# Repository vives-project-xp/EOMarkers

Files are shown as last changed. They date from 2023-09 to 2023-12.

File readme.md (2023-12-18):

# **EO-Markers**

> Develop small standalone boxes that light up when someone approaches them.
> The boxes can be fitted with a plexi with Electronics-ICT and a
> direction indication via an arrow.

# Layout Github Repo

```bash
.
├── 3d tekening
│   ├── 3D_Bottom.png
│   ├── 3D_Main.png
│   └── README.md
├── Affiche
│   └── EO Markers Affiche.png
├── AndroidStudio
│   ├── EO-Markers
│   │   └── app
│   └── README.md
├── Arduino
│   ├── EO-Markers
│   │   ├── EO-Markers.cpp
│   │   └── EXAMPLE-config.h
│   └── README.md
├── img
│   ├── qr.png
│   └── project_canvas.png
│   └── potentiometers.jpg
│   └── schakelaar.jpg
├── PCB
│   ├── PCB
|   ├── PCB_ESP32-C3-DevKitM-1
│   ├── PCB_ESP32-C3-DevKitC-02
│   └── README.md
└── readme.md
```

# Table of contents

- [Planning](#planning)
- [Canvas](#canvas)
- [Affiche](#affiche)
- [How to use](#how-to-use)
- [3D Tekening](#3d-drawing)
- [Android Studio](#android-studio)
- [Arduino](#arduino)
- [PCB](#pcb)

# Planning

- sprint 1 - Uitwerken concept & BOM lijst doorgeven voor bestellingen
- sprint 2 - Van prototype naar product
- sprint 3 - Product afwerken en test klaar maken
- sprint 4 - Debuggen, documenteren

# Canvas

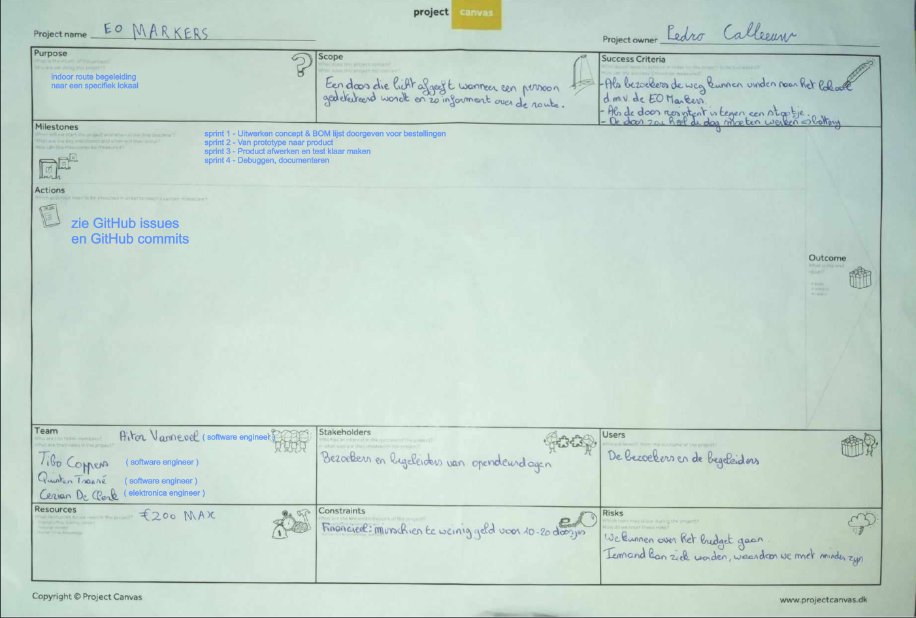
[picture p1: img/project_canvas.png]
Canvas


# Affiche

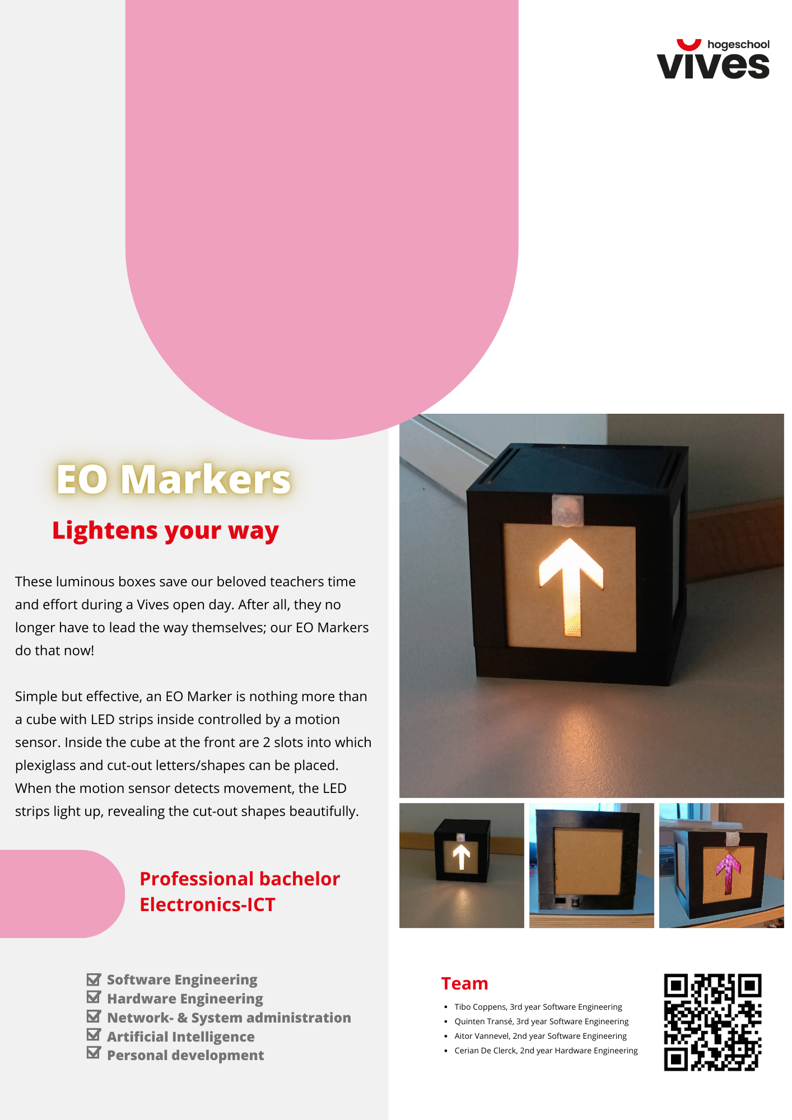
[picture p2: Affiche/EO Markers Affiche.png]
Affiche


# How to use

1. It is important that the batteries are fully charged, as they are rechargeable. A USB-C port is provided as an alternative power supply.
2. Turn the switch on.

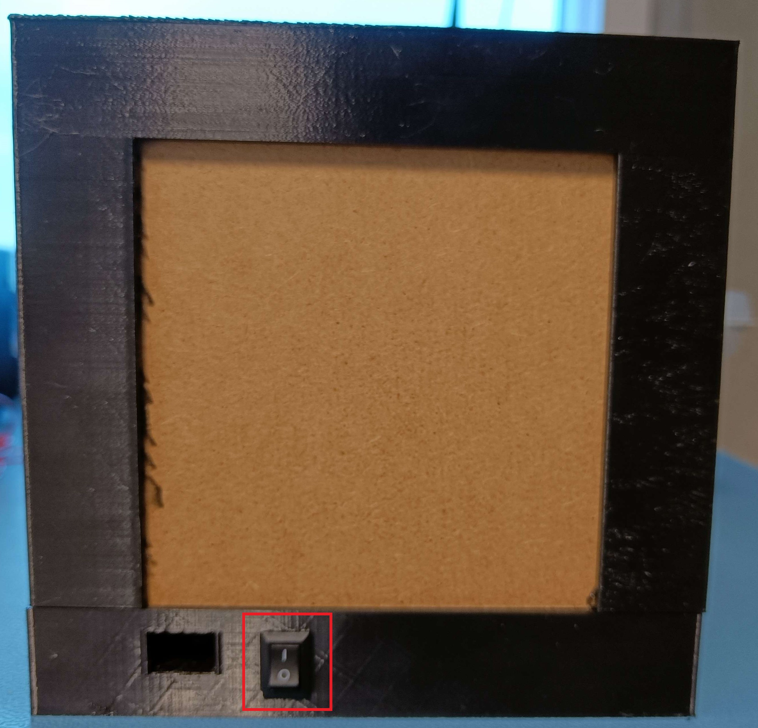
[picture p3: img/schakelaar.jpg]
schakelaar


3. Wait about 10 seconds. The LED strips will then light up whenever the sensor, attached to the front of the marker, detects movement.
4. You can change the distance at which the sensor detects movement and the duration of lighting by turning the potentiometers as shown in the image.

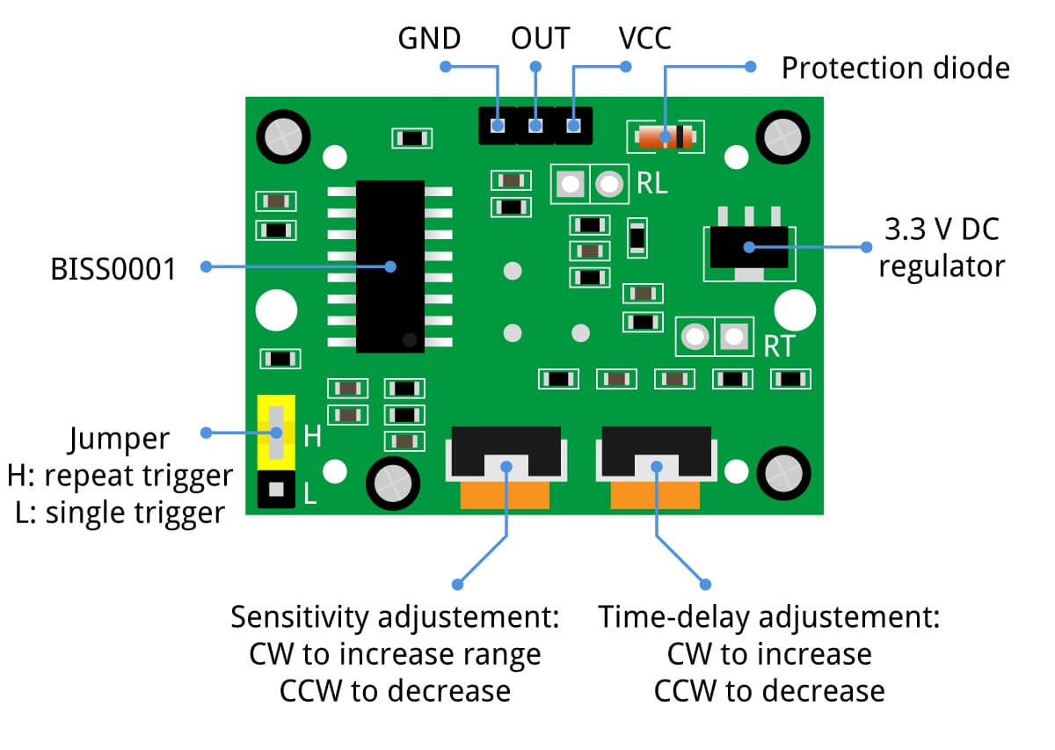
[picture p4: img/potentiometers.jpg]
potentiometers


5. Each time the light goes out, there is a period of 2.5 seconds before the sensor can detect movement again.
6. After using the EO marker, switch it off and charge the batteries.

# 3D drawing 

more info: [3D Tekening](./3d%20tekening/readme.md)

This is the base of the cube. The sensor is placed in the small round hole, the LED strips stick to the inside of the posts and the cables are inserted through the middle part. A reflective film has been applied to this area, which helps to spread the light around. A diffuser (plexiglass) is slid into the furthest slot and a plywood wall, with or without directions, is placed in the nearest slot.

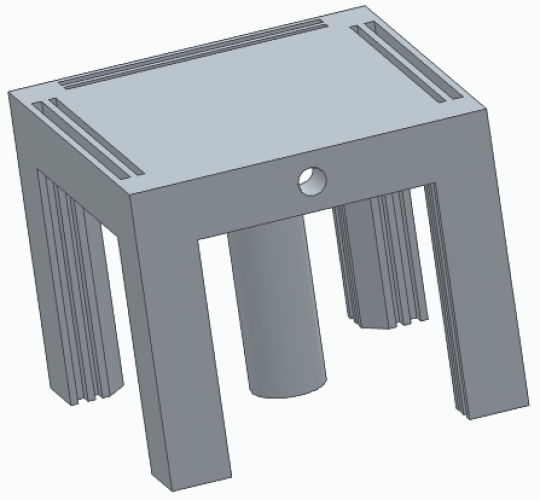
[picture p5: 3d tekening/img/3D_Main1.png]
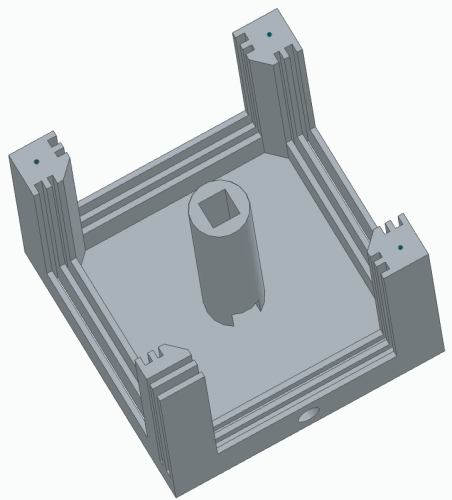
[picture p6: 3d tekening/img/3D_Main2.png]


This is the bottom of the cube. This is where the PCB, battery holder and cables end up. A hole is provided for a USB cable as secondary power. These 2 prints are screwed together with an M3 screw or bolt.

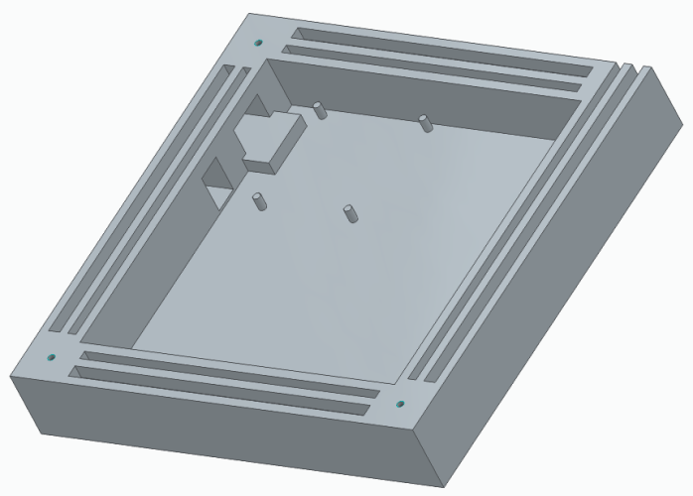
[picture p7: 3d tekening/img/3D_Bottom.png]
Bottom bottom


# Android Studio

more info: [Android Studio](./AndroidStudio/README.md)

# Arduino

more info: [Arduino](./Arduino/README.md)

# PCB

more info: [PCB](./PCB/README.md)

## PCB print

The PCB consists of a pair of connectors for the ESP, LED strip, sensor and USB-C port. These are female headers, so they fit in perfectly. The connectors are internally connected on the PCB. 

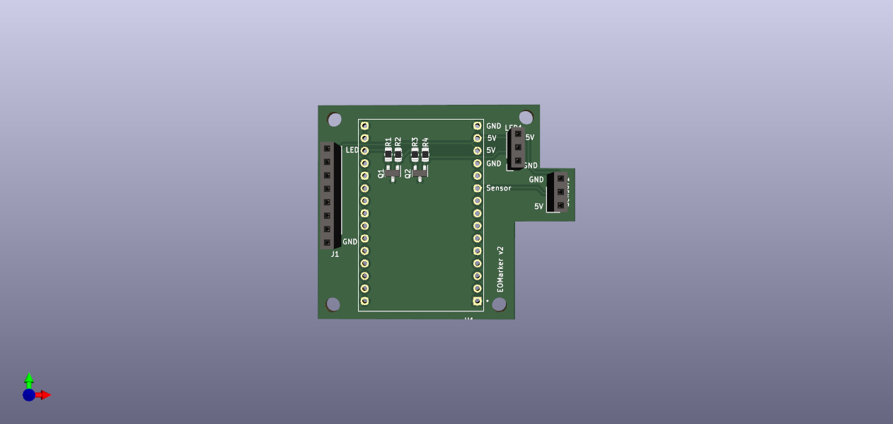
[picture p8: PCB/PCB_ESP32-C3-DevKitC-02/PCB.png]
PCB


## PCB schematic

The circuit consists of 1 ESP, powered by a USB cable or a 5V battery pack connected in parallel on the j1 connector with a diode from battery pack to connector (4 rechargeable AA batteries). 3 female headers for the LED strips, 3 female headers for the sensor, 8 female headers for the USB-C port and a diode to stop current to the batteries.

Measurements:
U LED-strips (off): 4,1V;
U LED-strips (on): 3,1V

U Batteries (leds off): 4.9V;
U Batteries (leds on): 4.3V

U Diode (leds off): 0.72V;
U Diode (leds on): 0.86V

U Sensor (leds off): 2.98V;
U Sensor (leds on): 2.55V

U ESP (leds off): 4.1V;
U ESP (leds on): 3.45V

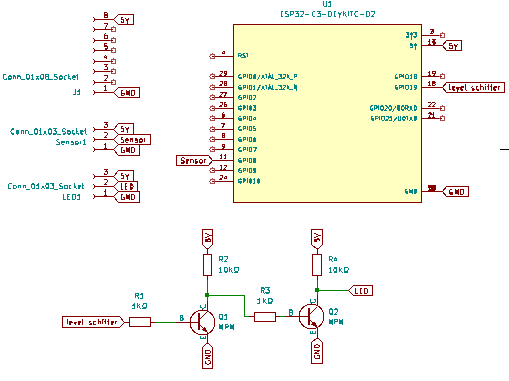
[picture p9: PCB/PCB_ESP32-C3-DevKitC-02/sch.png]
Schakeling


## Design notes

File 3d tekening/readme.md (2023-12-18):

# 3D drawing of EO-Marker

# Table of contents

- [Top part](#top)
- [Bottom Part](#bottom)
- [Wall](#wall)
- [Afmetingen](#afmetingen-metric)
- [Recommended Print Settings](#recommended-print-settings)

# Top

This is the main part of the cube. The sensor goes into the hole at the front with its cables going through the cylinder. A reflective foil is applied to this cylinder. The LED strips are located on the sloping side of the pillars. A diffuser (plexiglass) is placed in the furthest slot and a plywood wall, with or without directions, is placed in the nearest slot.

Top topTop top

# Bottom

This is the bottom of the cube. This is where the PCB and battery holder end up. These are glued in place with hot glue. There is a hole for a USB cable that functions as a secondary power and a hole for the switch. These 2 prints are screwed together with an M3 screw or bolt. The PCB is slid onto the pins with the USB-C connector on the platform. To the left of the switch, against the wall, the battery holder is glued with a margin between the 2 walls, so that it can be opened.

Bottom bottom

# Wall

This is the wall that blocks or allows light to pass through an arrow. This is laser cut from 3mm plywood. A reflective foil is also applied to this on the inside, so that the light can only escape through the arrow.

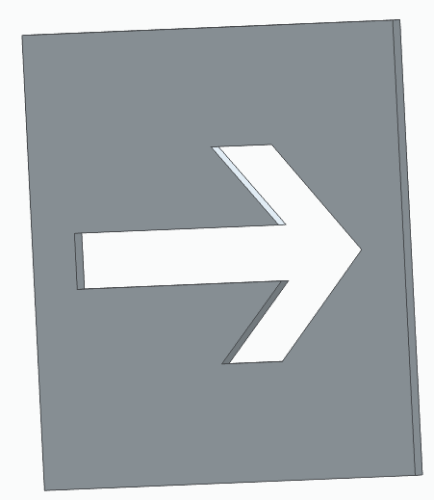
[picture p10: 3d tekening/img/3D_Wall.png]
Wall wall


# Afmetingen (metric)

The cube assembled is 150x150x150 mm in size. The walls have a size of 109x109x3 mm, of which 100x100 mm is visible.

# Recommended print settings

- Material: PLA
- Resolution: 0.15 - 0.20
- Infill density: 10%
- Infill pattern: tri-hexagon
- Support: tree
- No adhesion

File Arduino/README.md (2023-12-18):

# arduino (esp32) firmware

## table of contents

- [Setup and configuration](#setup-and-configuration)
  - [Install environment](#install-environment)
  - [Configure config.h](#configure-configh)
- [Install](#install)
- [Usage](#usage)
- [Flowchart](#flowchart)

## Setup and configuration

Clone this repository and open it in vscode with platformio installed.

Open ./EOMarker_firm in vscode.

### Install environment

1. Install vscode
2. Install platformio
3. Select esp32 board

### Configure config.h

1. Copy `config.h.example` to `config.h`
2. Configure `config.h` with your wifi and mqtt settings

Example config.h:
```cpp
namespace EOMarker {
  namespace Config  {
    const char * WIFI_SSID = "SSID";
    //const char * WIFI_PASS = "PASSWORD";
    const char * MQTT_BROKER = "BROKER_URL";
    const char * MQTT_PASS = "BROKER_PASSWORD";
    const unsigned int MQTT_PORT = BROKER_PORT;
    const char * MQTT_BASE_TOPIC = "MQTT_TOPIC";
    const String LOGINS = "{'MAC-ADDRESS':'PASSWORD','MAC-ADDRESS2':'PASSWORD2'}";
  };
};
```

## Install

1. Connect esp32 to computer
2. Run `pio run -t upload`

## Usage

1. Connect esp32 to custom pcb
2. Turn on switch

# Flowchart

this is an attempt to visualize the flow of the program (not accurate) 

```mermaid
graph TD
    A[main] --> B[setup]
    B --> C[loop]
    C --> D[setup_wifi]
    D --> E[keepWifiAlive]
    E --> F[checkSensor]
    F --> G[setColor]
    G --> H[sendAlive]
    H --> I[convertMac]
    I --> J[reconnect]
    J --> C
    J --> K[callback]
    K --> L[setColor]
    L --> H
    L --> M[sendAlive]
    M --> N[convertMac]
    N --> J
    N --> O[reconnect]
    O --> C
    O --> P[setColor]
    P --> Q[sendAlive]
    Q --> R[convertMac]
    R --> O
    R --> S[reconnect]
    S --> C
    S --> T[setColor]
    T --> U[sendAlive]
    U --> V[convertMac]
    V --> S
    V --> W[reconnect]
    W --> C
    W --> X[setColor]
    X --> Y[sendAlive]
    Y --> Z[convertMac]
    Z --> W
    
```

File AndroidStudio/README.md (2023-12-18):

# The android app
## Table of contents

- [How to install](#how-to-install)
- [How to use](#how-to-use)

## How to install

1. Download the apk file from the [EOMarker_v1.0.apk](EOMarker_V1.0.apk).
2. Install the apk file on your android device.

## How to use

1. Open the app.
2. Go to settings and fill in the broker credentials.

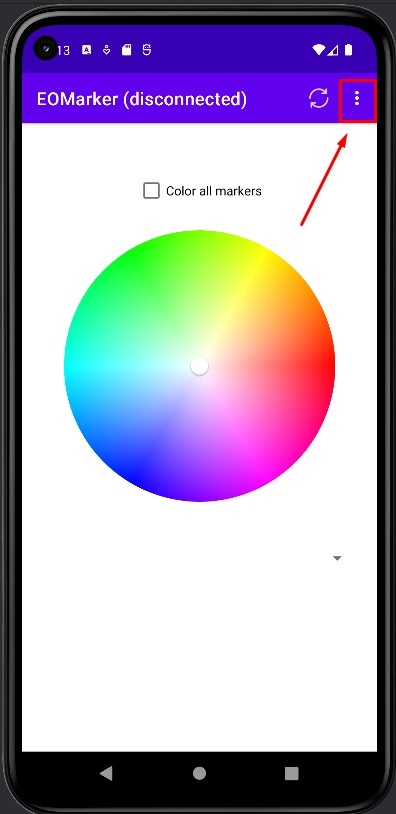
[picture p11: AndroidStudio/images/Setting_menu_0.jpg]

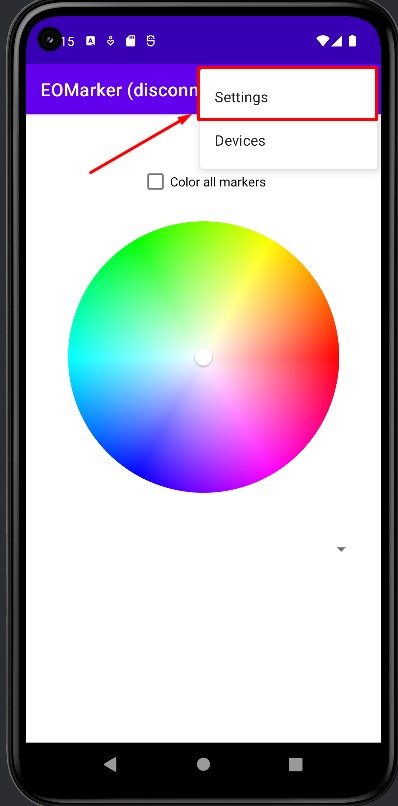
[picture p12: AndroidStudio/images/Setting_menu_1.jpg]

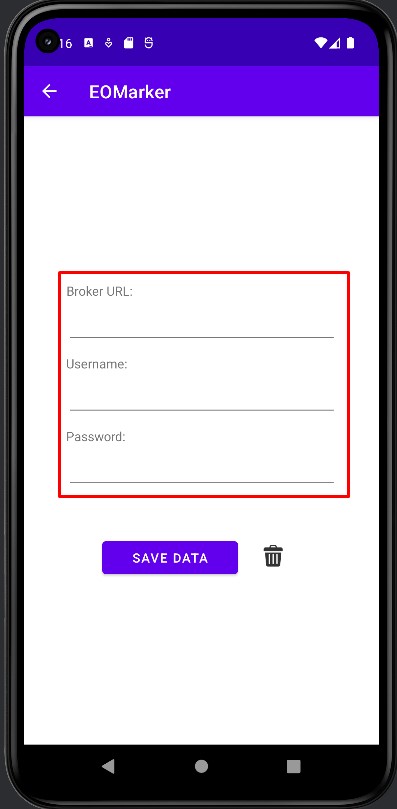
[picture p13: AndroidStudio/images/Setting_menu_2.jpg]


3. When you've filled in the credentials save them by pressing the save button.

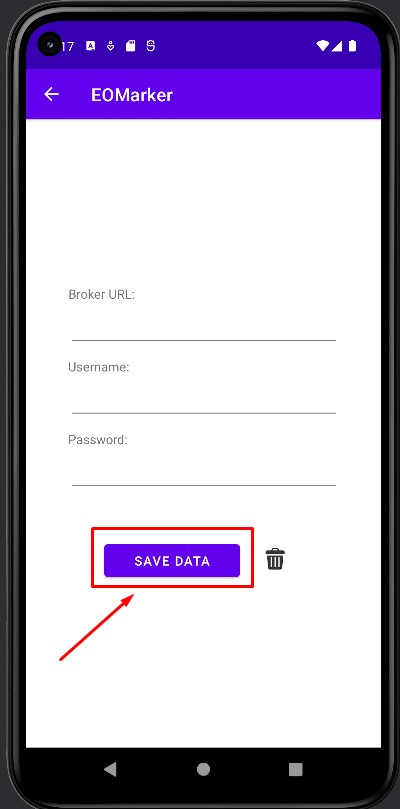
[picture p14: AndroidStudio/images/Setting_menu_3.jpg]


4. You should be redirected to the main menu and the status should now show connected instead of disconnected. 

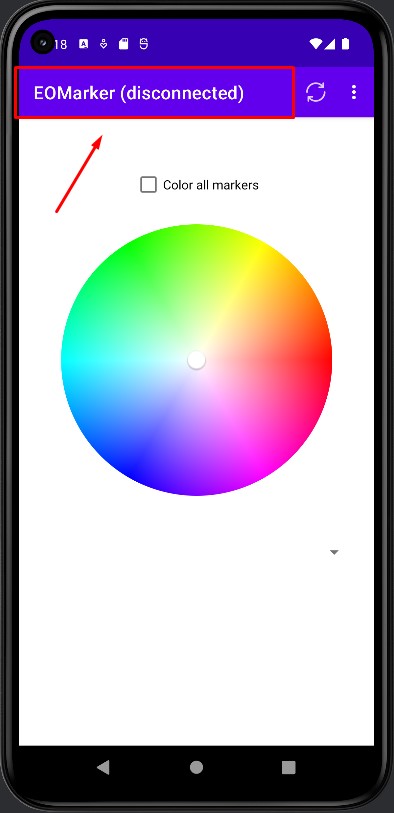
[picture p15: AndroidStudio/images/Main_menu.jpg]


5. Click the refresh button to discover the list of devices that are connected to the broker if available.

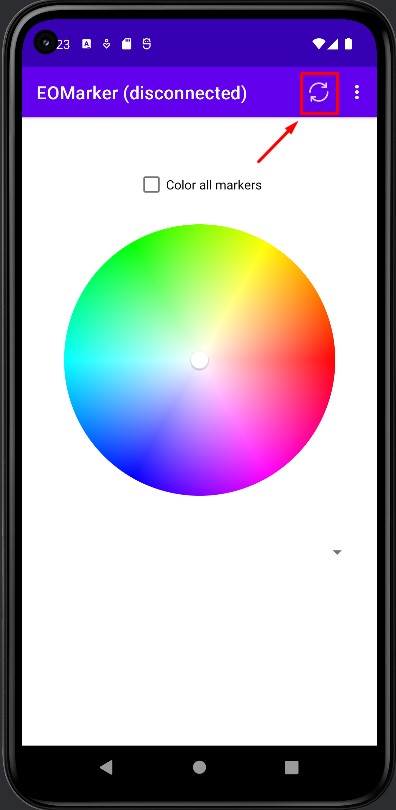
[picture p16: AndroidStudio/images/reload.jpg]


6. The dropdown menu should now be filled with the devices that are connected to the broker.

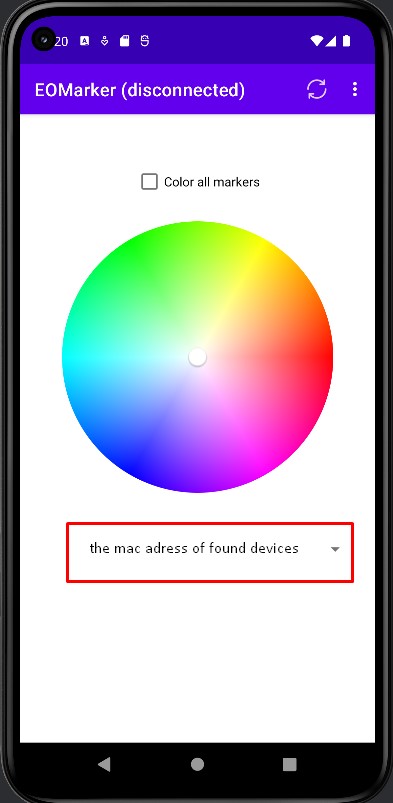
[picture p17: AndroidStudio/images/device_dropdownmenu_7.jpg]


7. Go to options and select devices.

settings
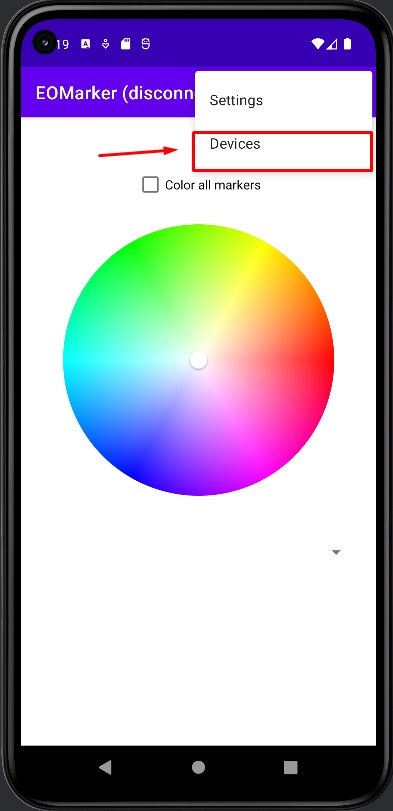
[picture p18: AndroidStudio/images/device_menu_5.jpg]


8. You should see a list of devices that are connected to the broker.
9. Click on the visualizer button to visualize the selected device or all devices.

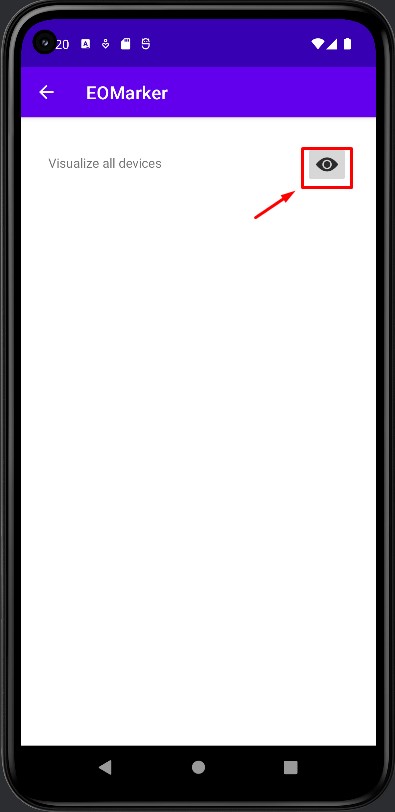
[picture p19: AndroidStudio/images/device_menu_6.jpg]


10. In the main menu you can select a color and set it to the selected device or all devices by using the checkbox.

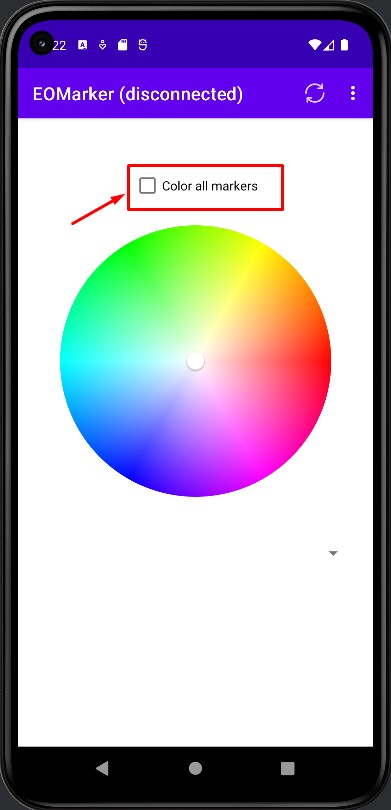
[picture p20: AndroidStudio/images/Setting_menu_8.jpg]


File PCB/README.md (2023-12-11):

# PCB For EO-Marker

## Important Note

Use PCB_ESP32-C3-DevKitM-1 or PCB_ESP32-C3-DevKitC-02
but the pinout is the ***not*** same for both!

Physical layout is the same but the pinout is different.

Make sure to use the right code for the right esp32-c3-devkit.

Pinout:

|component|ESP32-C3-DevKitM-1|ESP32-C3-DevKitC-02|
|---|---|---|
|LED|GPIO 18|GPIO 19|
|Sensor|GPIO 10|GPIO 8|

## Table of Contents

- [layout](#layout)
- [PCB](#pcb-deprecated)
- [PCB_ESP32-C3-DevKitM-1](#pcb_esp32-c3-devkitc-02)
- [PCB_ESP32-C3-DevKitC-02](#pcb_esp32-c3-devkitc-02)

## layout

```bash
.
├── README.md
├── pcb
├── PCB_ESP32-C3-DevKitM-1
├── PCB_ESP32-C3-DevKitC-02

```

## PCB DEPRECATED

First version of PCB for EOMaker
is only for ESP32-C3-DevKitM-1.

Schematic and PCB:

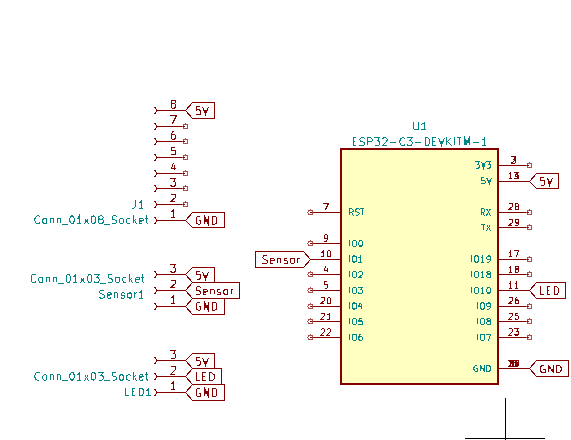
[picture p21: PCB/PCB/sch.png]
PCB schematic


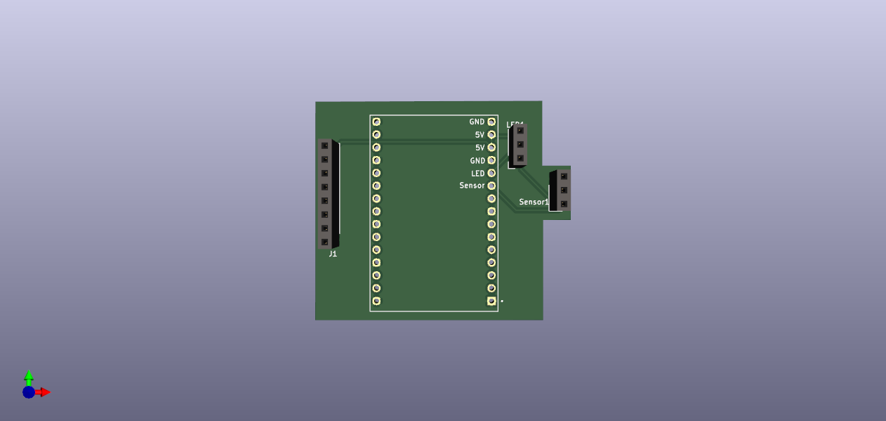
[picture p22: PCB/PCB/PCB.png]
PCB


### BOM

| Part | Value | Package | Description |
| --- | --- | --- | --- |
| J1 | Conn_01x08_Socket | Connector_PinSocket_2.54mm:PinSocket_1x08_P2.54mm_Vertical | Generic connector, single row, 01x08, script generated |
| LED1 | Conn_01x03_Socket | Connector_PinSocket_2.54mm:PinSocket_1x03_P2.54mm_Vertical | Generic connector, single row, 01x03, script generated |
| Sensor1 | Conn_01x03_Socket | Connector_PinSocket_2.54mm:PinSocket_1x03_P2.54mm_Vertical | Generic connector, single row, 01x03, script generated |
| U1 | ESP32-C3-DEVKITM-1 | ESP32-C3-DEVKITM-1:XCVR_ESP32-C3-DEVKITM-1 |  |

## PCB_ESP32-C3-DevKitM-1

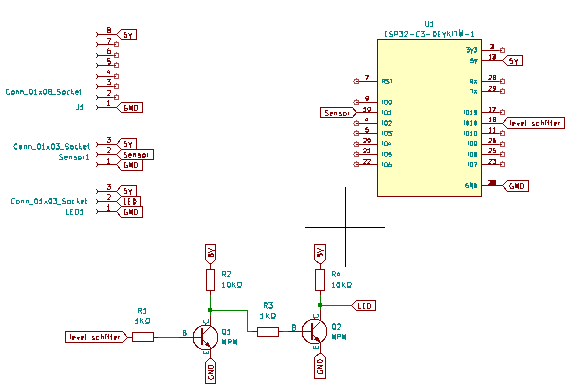
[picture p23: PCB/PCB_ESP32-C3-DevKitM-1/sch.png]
PCB_ESP32-C3-DevKitM-1


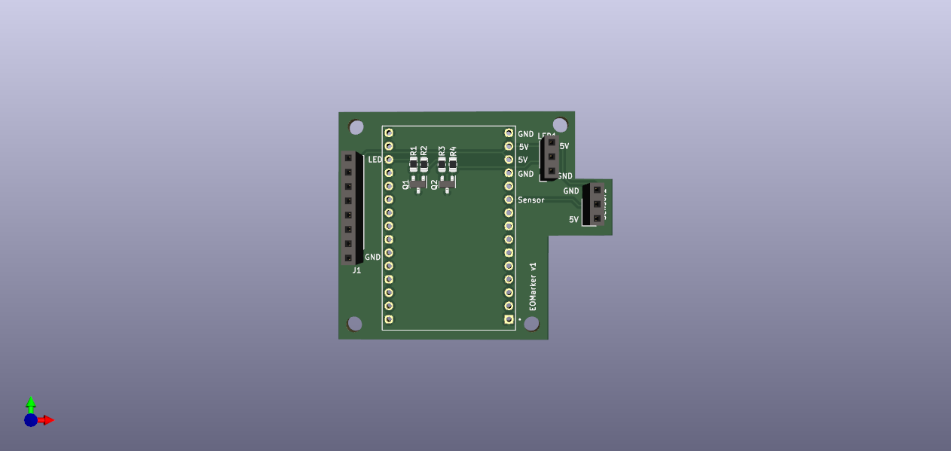
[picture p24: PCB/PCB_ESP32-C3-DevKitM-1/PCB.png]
PCB_ESP32-C3-DevKitM-1


### bom PCB_ESP32-C3-DevKitM-1

| Part | Value | Package | Description |
| --- | --- | --- | --- |
| J1 | Conn_01x08_Socket | Connector_PinSocket_2.54mm:PinSocket_1x08_P2.54mm_Vertical | Generic connector, single row, 01x08, script generated |
| LED1 | Conn_01x03_Socket | Connector_PinSocket_2.54mm:PinSocket_1x03_P2.54mm_Vertical | Generic connector, single row, 01x03, script generated |
| Q1, Q2 | NPN | Package_TO_SOT_SMD:SOT-23 | Bipolar transistor symbol for simulation only, substrate tied to the emitter |
| R1, R3 | 1KΩ | Resistor_SMD:R_0805_2012Metric | Resistor |
| R2, R4 | 10KΩ | Resistor_SMD:R_0805_2012Metric | Resistor |
| Sensor1 | Conn_01x03_Socket | Connector_PinSocket_2.54mm:PinSocket_1x03_P2.54mm_Vertical | Generic connector, single row, 01x03, script generated |
| U1 | ESP32-C3-DEVKITM-1 | ESP32-C3-DEVKITM-1:XCVR_ESP32-C3-DEVKITM-1 |  |

## PCB_ESP32-C3-DevKitC-02

PCB_ESP32-C3-DevKitC-02

PCB_ESP32-C3-DevKitC-02

### bom PCB_ESP32-C3-DevKitM-02

| Part | Value | Package | Description |
| --- | --- | --- | --- |
| J1 | Conn_01x08_Socket | Connector_PinSocket_2.54mm:PinSocket_1x08_P2.54mm_Vertical | Generic connector, single row, 01x08, script generated |
| LED1 | Conn_01x03_Socket | Connector_PinSocket_2.54mm:PinSocket_1x03_P2.54mm_Vertical | Generic connector, single row, 01x03, script generated |
| Q1, Q2 | NPN | Package_TO_SOT_SMD:SOT-23 | Bipolar transistor symbol for simulation only, substrate tied to the emitter |
| R1, R3 | 1KΩ | Resistor_SMD:R_0805_2012Metric | Resistor |
| R2, R4 | 10KΩ | Resistor_SMD:R_0805_2012Metric | Resistor |
| Sensor1 | Conn_01x03_Socket | Connector_PinSocket_2.54mm:PinSocket_1x03_P2.54mm_Vertical | Generic connector, single row, 01x03, script generated |
| U1 | ESP32-C3-DEVKITC-02 | ESP32-C3-DEVKITC-02:XCVR_ESP32-C3-DEVKITC-02 |  |

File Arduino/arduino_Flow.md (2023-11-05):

# code flow

```
+----------------------------------------+
|  Global Variable Declarations  
|    Include Libraries     
|    Define Constants     
|    Create NeoPixel Object  
+----------------------------------------+
        |
        v
+----------------------------------------+
|          setup() Function            
|    Initialize Serial                
|    Set Sensor Pin as Input         
|    Initialize NeoPixel LED Strip   
|    Initialize EEPROM and Read Color
|    Create checkSensor Task         
|    Configure WiFi and MQTT         
+----------------------------------------+
        |
        v
+----------------------------------------+
|         loop() Function              
|      MQTT Client Loop                
+----------------------------------------+
        |
        v
+----------------------------------------+
|        setup_wifi() Function      
|    Create keepWifiAlive Task       
+----------------------------------------+
        |
        v
+----------------------------------------+
|       callback() Function            
|   Handle MQTT Messages              
|   Parse and Convert Colors         
|   Write to EEPROM                   
|   Set LED Color and Show           
+----------------------------------------+
        |
        v
+----------------------------------------+
|      reconnect() Function         
|   MQTT Reconnection Logic          
+----------------------------------------+
        |
        v
+----------------------------------------+
|      setColor() Function          
|   Set LED Color                    
+----------------------------------------+
        |
        v
+----------------------------------------+
|      sendAlive() Function         
|   Publish "alive" Message         
+----------------------------------------+
        |
        v
+----------------------------------------+
|      convertMac() Function       
|   Convert MAC Address              
+----------------------------------------+
        |
        v
+----------------------------------------+
|    keepWifiAlive() Function     
|   Ensure Continuous WiFi          
|   Connect and Reconnect          
+----------------------------------------+
        |
        v
+----------------------------------------+
|    checkSensor() Function         
|   Continuous Sensor Monitoring   
|   Update LED and Publish         
+----------------------------------------+
```

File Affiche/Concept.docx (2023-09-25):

EO MARKERS

QR Code github / Filmpje?

Beetje uitleg

Foto’s tijdens gebruik

Product

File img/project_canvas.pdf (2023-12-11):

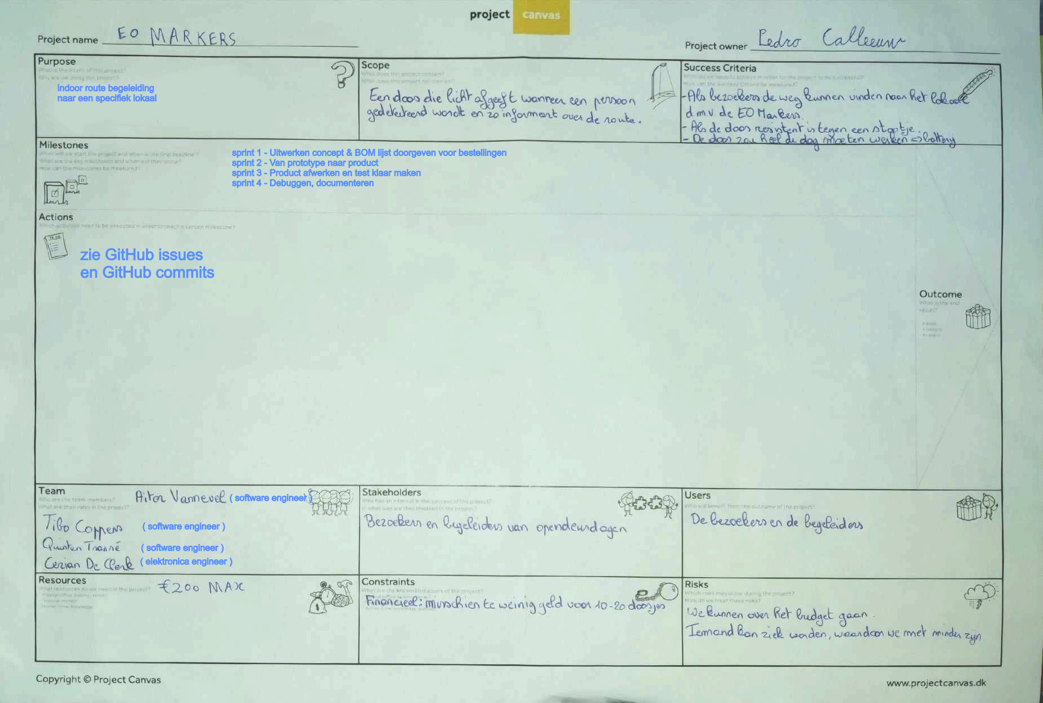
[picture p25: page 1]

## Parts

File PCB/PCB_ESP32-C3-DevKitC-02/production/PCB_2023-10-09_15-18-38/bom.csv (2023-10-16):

Designator | Footprint | Quantity | Value | LCSC Part #
J1 | PinSocket_1x08_P2.54mm_Vertical | 1 | Conn_01x08_Socket
LED1, Sensor1 | PinSocket_1x03_P2.54mm_Vertical | 2 | Conn_01x03_Socket
U1 | XCVR_ESP32-C3-DEVKITM-1 | 1 | ESP32-C3-DEVKITM-1

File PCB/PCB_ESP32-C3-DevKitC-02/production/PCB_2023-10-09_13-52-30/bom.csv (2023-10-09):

Designator | Footprint | Quantity | Value | LCSC Part #
LED, Sensor | PinSocket_1x03_P2.54mm_Vertical | 2 | Conn_01x03_Socket
U1 | XCVR_ESP32-C3-DEVKITM-1 | 1 | ESP32-C3-DEVKITM-1

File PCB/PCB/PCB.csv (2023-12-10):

Source: | C:\Users\tibo\Desktop\EOMarkers\PCB\PCB\PCB.kicad_sch
Date: | 10/12/2023 15:05:10
Tool: | Eeschema 7.0.7
Generator: | C:\Program Files\KiCad\7.0\bin\scripting\plugins/bom_csv_grouped_by_value_with_fp.py
Component Count: | 4
Ref | Qnty | Value | Cmp name | Footprint | Description | Vendor | DNP
J1 | 1 | Conn_01x08_Socket | Conn_01x08_Socket | Connector_PinSocket_2.54mm:PinSocket_1x08_P2.54mm_Vertical | Generic connector, single row, 01x08, script generated
LED1 | 1 | Conn_01x03_Socket | Conn_01x03_Socket | Connector_PinSocket_2.54mm:PinSocket_1x03_P2.54mm_Vertical | Generic connector, single row, 01x03, script generated
Sensor1 | 1 | Conn_01x03_Socket | Conn_01x03_Socket | Connector_PinSocket_2.54mm:PinSocket_1x03_P2.54mm_Vertical | Generic connector, single row, 01x03, script generated
U1 | 1 | ESP32-C3-DEVKITM-1 | ESP32-C3-DEVKITM-1 | ESP32-C3-DEVKITM-1:XCVR_ESP32-C3-DEVKITM-1

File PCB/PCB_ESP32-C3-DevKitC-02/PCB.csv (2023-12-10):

Source: | C:\Users\tibo\Desktop\EOMarkers\PCB\PCB_ESP32-C3-DevKitC-02\PCB.kicad_sch
Date: | 10/12/2023 15:09:07
Tool: | Eeschema 7.0.7
Generator: | C:\Program Files\KiCad\7.0\bin\scripting\plugins/bom_csv_grouped_by_value_with_fp.py
Component Count: | 10
Ref | Qnty | Value | Cmp name | Footprint | Description | Vendor | DNP
J1 | 1 | Conn_01x08_Socket | Conn_01x08_Socket | Connector_PinSocket_2.54mm:PinSocket_1x08_P2.54mm_Vertical | Generic connector, single row, 01x08, script generated
LED1 | 1 | Conn_01x03_Socket | Conn_01x03_Socket | Connector_PinSocket_2.54mm:PinSocket_1x03_P2.54mm_Vertical | Generic connector, single row, 01x03, script generated
Q1, Q2 | 2 | NPN | NPN | Package_TO_SOT_SMD:SOT-23 | Bipolar transistor symbol for simulation only, substrate tied to the emitter
R1, R3 | 2 | 1KΩ | R | Resistor_SMD:R_0805_2012Metric | Resistor
R2, R4 | 2 | 10KΩ | R | Resistor_SMD:R_0805_2012Metric | Resistor
Sensor1 | 1 | Conn_01x03_Socket | Conn_01x03_Socket | Connector_PinSocket_2.54mm:PinSocket_1x03_P2.54mm_Vertical | Generic connector, single row, 01x03, script generated
U1 | 1 | ESP32-C3-DEVKITC-02 | ESP32-C3-DEVKITC-02 | ESP32-C3-DEVKITC-02:XCVR_ESP32-C3-DEVKITC-02

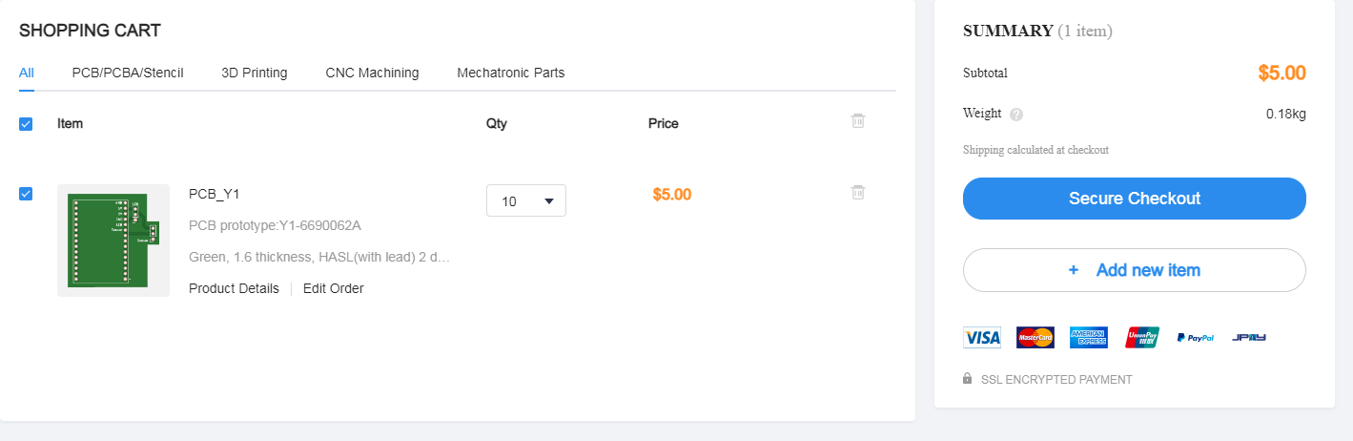
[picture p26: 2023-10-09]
PCB/shopping cart.png

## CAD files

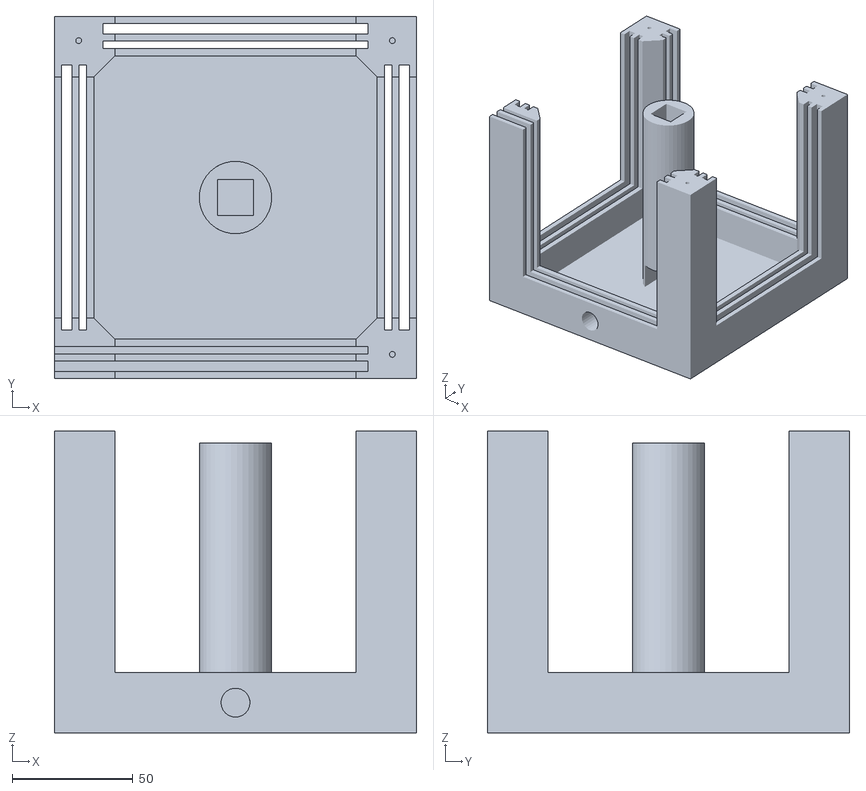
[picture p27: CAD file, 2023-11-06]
3d tekening/main part.stl
150.0 x 150.0 x 125.0

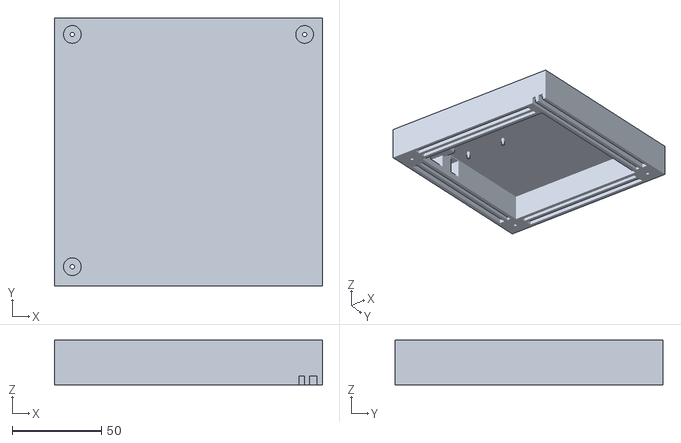
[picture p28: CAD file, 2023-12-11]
3d tekening/bottom.stl
150.0 x 150.0 x 25.0

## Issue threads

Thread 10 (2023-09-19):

testen van bewegingsensor HC-SR501

Quinten331, 2023-09-19:

imawizzard, 2023-09-25:
Sensor getest. Mogelijkheid om de afstand en tijd in te stellen.
Afstand: 0m - 4m
Tijd: 2s - 200s

Je kan de sensor instellen zodat hij constant blijf detecteren zolang er een persoon aanwezig is, of dat hij altijd na de ingestelde tijd uitschakelt.

https://www.mpja.com/download/31227sc.pdf
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

Closed 2023-09-25.

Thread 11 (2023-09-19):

first draft box 3d tekenen

Quinten331, 2023-09-19:

Quinten331, 2023-10-02:
150mm*150mm*150mm groot, met een inschuifslot voor een plaatje met de grootte van 108mm*108mm*3mm aan alle 4 de kanten. Ook plaats voor 4 acrylic platen met dimensies 108mm*108mm*3mm. In de onderkant komt alle electronica te liggen en in het gat in de bovenkant komt de sensor. Onderaan is er ook een rechthoek uitgesneden voor de micro-USB kabel.

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

Closed 2023-10-08.

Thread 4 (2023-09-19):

Tekst toevoegen aan Affiche

Quinten331, 2023-09-19:

declerckcerian, 2023-10-02:
Ik heb de template die aangeboden werd, overgenomen en concept uitgewerkt voor onze affiche. Titel, subtitel en korte uitleg van het project staan reeds vermeld, net zoals de vermelding van het team. Enkel over foto's op de affiche moet nog nagedacht worden.

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

pcvives, 2023-10-03:
Done... en je moet nog nadenken over de foto's ;)

Closed 2023-10-02.

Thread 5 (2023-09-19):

Prototype bouwen

Quinten331, 2023-09-19:

imawizzard, 2023-09-25:
Eerste prototype gemaakt.
We gebruiken een transistor als schakelaar. Zo kunnen we met het signaal van de pir sensor onze ledstrip doen branden.

https://github.com/vives-project-xp/EOMarkers/assets/41449816/e3350e2a-bc32-47cf-bbb6-c784382c6e3d

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

Closed 2023-10-16.

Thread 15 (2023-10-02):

Foto's toevoegen aan affiche

declerckcerian, 2023-10-02:
Er moeten nog een drietal foto's toegevoegd worden aan de affiche om wat meer visualisatie op de affiche te creëren.
Mogelijke foto's:
-eentje van het project, volledig afgewerkt
-eentje waarbij de ledstrips uitgeschakeld zijn
-eentje waarbij de ledstrips aan zijn wanneer beweging gedetecteerd wordt, om zo het concept van het product voor te stellen

Closed 2023-12-16.

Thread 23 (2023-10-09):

Ledstrips doorknippen

declerckcerian, 2023-10-09:
We nemen een rol van 5m aan RGB ledstrips. We kiezen ervoor om 24 ledjes per doos te gebruiken, en aan elke kant van de doos hangen we 6 ledstrips zodat de volledige doos mooi verlicht is.

Closed 2023-10-09.

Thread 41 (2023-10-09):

Sensor testen

declerckcerian, 2023-10-09:
We hadden een probleem met de sensor die niet meer wou werken. We testen deze nog eens apart om te zien of het nog werkt of niet in een simpele schakeling met een weerstand en led.

Closed 2023-12-16.

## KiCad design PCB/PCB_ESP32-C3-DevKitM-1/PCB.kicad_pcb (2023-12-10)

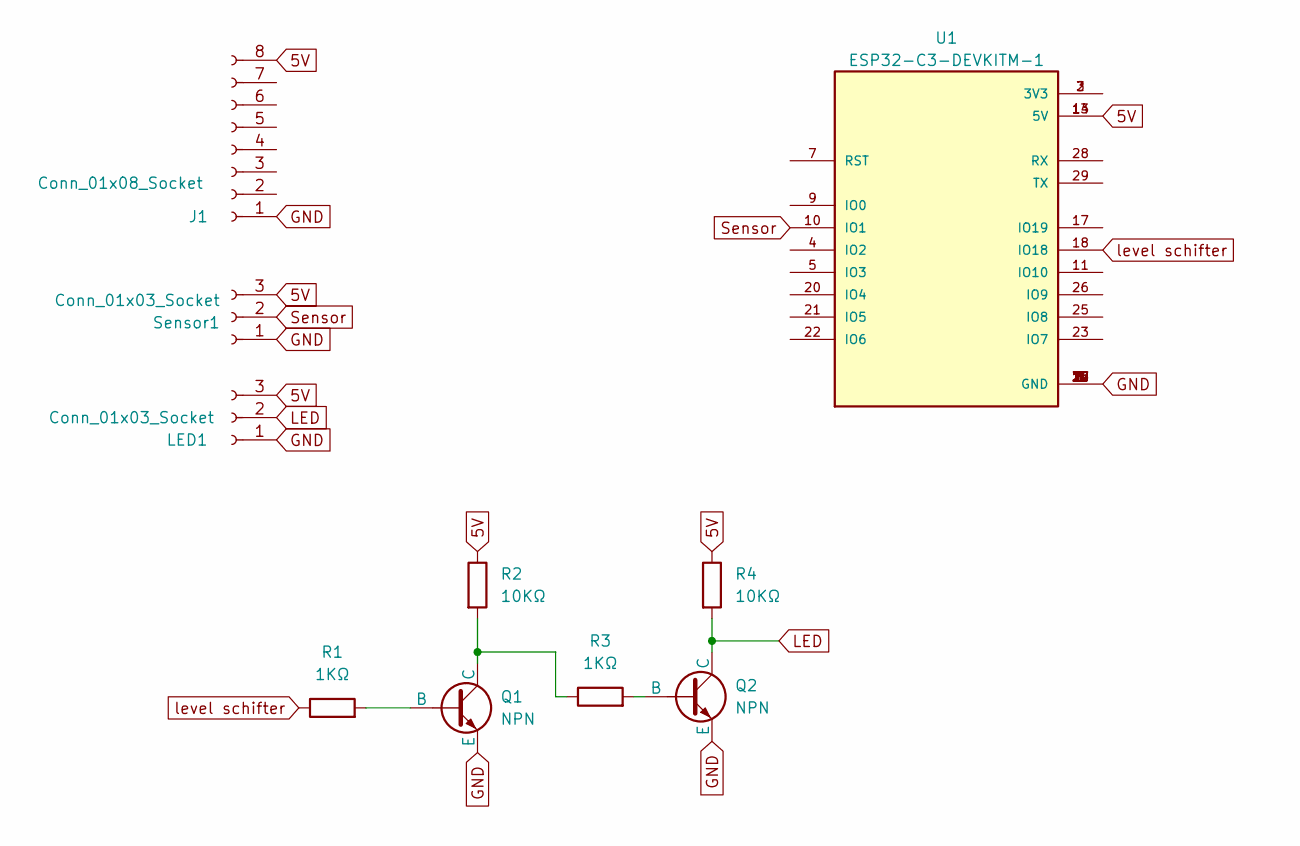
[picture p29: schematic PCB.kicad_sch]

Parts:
J1: Conn_01x08_Socket; PinSocket_1x08_P2.54mm_Vertical
LED1: Conn_01x03_Socket; PinSocket_1x03_P2.54mm_Vertical
Q1, Q2: NPN; SOT-23
R1, R3: 1KΩ; R_0805_2012Metric
R2, R4: 10KΩ; R_0805_2012Metric
Sensor1: Conn_01x03_Socket; PinSocket_1x03_P2.54mm_Vertical
U1: ESP32-C3-DEVKITM-1; XCVR_ESP32-C3-DEVKITM-1

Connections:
5V: J1.8, LED1.3, R2.1, R4.1, Sensor1.3, U1.13 (5V), U1.14 (5V)
GND: J1.1, LED1.1, Q1.3 (E), Q2.3 (E), Sensor1.1, U1.1 (GND), U1.6 (GND), U1.8 (GND), U1.12 (GND), U1.15 (GND), U1.16 (GND), U1.19 (GND), U1.24 (GND), U1.27 (GND), U1.30 (GND)
LED: LED1.2, Q2.1 (C), R4.2
unnamed: Q1.2 (B), R1.2
unnamed: Q1.1 (C), R2.2, R3.1
unnamed: Q2.2 (B), R3.2
unnamed: U1.2 (3V3), U1.3 (3V3)
Sensor: Sensor1.2, U1.10 (IO1)
level schifter: R1.1, U1.18 (IO18)

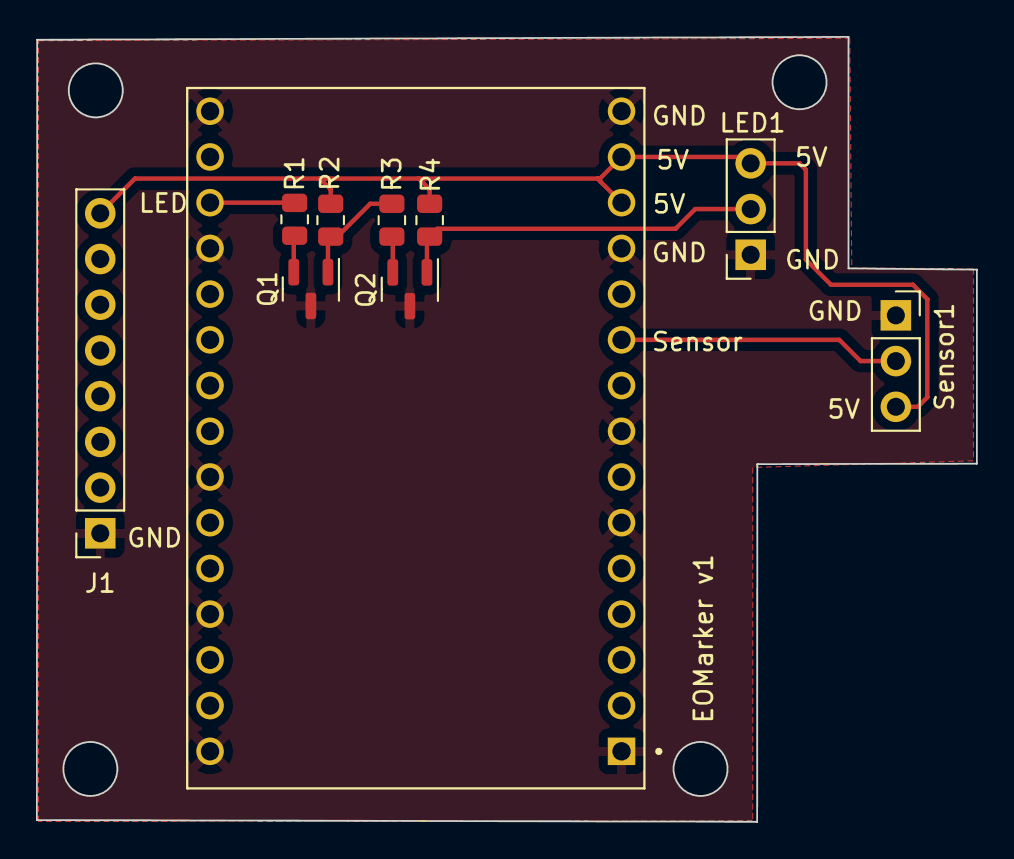
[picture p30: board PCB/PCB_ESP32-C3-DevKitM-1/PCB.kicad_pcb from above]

Board: 2 copper layers, 52.2 x 43.6 mm, 10 parts (0 on the bottom side), 9 nets.

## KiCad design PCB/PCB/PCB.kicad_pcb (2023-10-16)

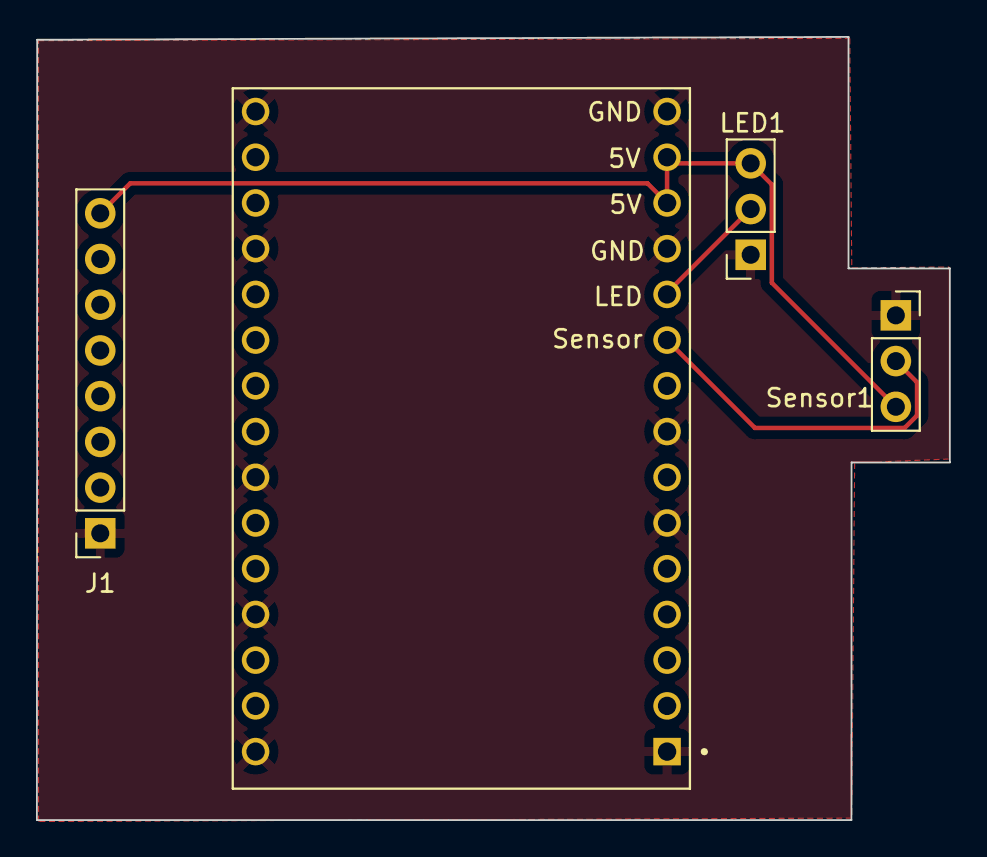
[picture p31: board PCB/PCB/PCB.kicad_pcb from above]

Board: 2 copper layers, 50.7 x 43.5 mm, 4 parts (0 on the bottom side), 5 nets.

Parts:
J1: USB-C; PinSocket_1x08_P2.54mm_Vertical
LED1: Conn_01x03_Socket; PinSocket_1x03_P2.54mm_Vertical
Sensor1: Conn_01x03_Socket; PinSocket_1x03_P2.54mm_Vertical
U1: ESP32-C3-DEVKITM-1; XCVR_ESP32-C3-DEVKITM-1

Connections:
5V: J1.8, LED1.3, Sensor1.3, U1.13 (5V), U1.14 (5V)
GND: J1.1, LED1.1, Sensor1.1, U1.1 (GND), U1.6 (GND), U1.8 (GND), U1.12 (GND), U1.15 (GND), U1.16 (GND), U1.19 (GND), U1.24 (GND), U1.27 (GND), U1.30 (GND)
LED: LED1.2, U1.11 (IO10)
unnamed: U1.2 (3V3), U1.3 (3V3)
Sensor: Sensor1.2, U1.10 (IO1)

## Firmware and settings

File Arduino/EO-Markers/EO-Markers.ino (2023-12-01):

#include <Adafruit_NeoPixel.h>
#include <WiFi.h>
#include <PubSubClient.h>
#include <EEPROM.h>
#include "config.h"
#include <RGBWConverter.h>
#include <ArduinoJson.h>
#define WIFI_TIMEOUT_MS 20000

// Namespace voor configuratievariabelen
using namespace EOMarker;
// Definieer hardware-gerelateerde constanten
#define PIN 10            // De ESP32-pin GPIO16 verbonden met sk6812                                                           ################ ESP-C3 V1
#define NUM_PIXELS 24    // Het aantal LED's (pixels) op de sk6812 LED-strip
Adafruit_NeoPixel sk6812(NUM_PIXELS, PIN, NEO_GRBW + NEO_KHZ800);

// WiFi- en MQTT-clientinstellingen
WiFiClient espClient;
PubSubClient client(espClient);
String topic = Config::MQTT_BASE_TOPIC;
String friendlyName = "";


RGBWConverter converter(250, 250, 250, true);
// Pin voor sensorinput en kleurvariabelen
int sensorpin = 1; //                                                                                                            ################ ESP-C3 V1
int r = 0;
int g = 0;
int b = 0;
int w = 0;

bool prevVal = false;

void setup() {
  Serial.begin(115200);
  pinMode(sensorpin, INPUT);

  // Initialiseer sk6812 LED-strip
  sk6812.begin();

  // EEPROM-initialisatie en ophalen van opgeslagen kleurwaarden
  EEPROM.begin(512);
  r = EEPROM.read(0);
  g = EEPROM.read(1);
  b = EEPROM.read(2);
  w = EEPROM.read(3);
  friendlyName = readStringFromEEPROM(4);
  if(friendlyName.startsWith("name:")){
    friendlyName = friendlyName.substring(5); // Verwijder "name:" van de tekenreeks
    }else{
        friendlyName = "new Device";
  }
  if(r == 0 && g == 0 && b == 0){
    r = 255;
    g = 255;
    b = 255;
  }

  Serial.println("Lezen van EEPROM:");
  Serial.println("Rood: " + String(r));
  Serial.println("Groen: " + String(g));
  Serial.println("Blauw: " + String(b));
  Serial.println("Name: " + String(friendlyName));

  xTaskCreate(
    &checkSensor,  //function name
    "Keep Wifi Alive", //task name
    10240, //stack size increase above 1000 for connect to wifi
    NULL, //task parameters
    1, //priority
    NULL //task handle
  ); 

    // WiFi- en MQTT-configuratie
  setup_wifi();
  client.setServer(Config::MQTT_BROKER, Config::MQTT_PORT);
  client.setCallback(callback);
}

void loop() {
  client.loop();
}

// WiFi-configuratie
void setup_wifi() { 
  //Wifi setup
  xTaskCreatePinnedToCore(
    keepWifiAlive,  //function name
    "Keep Wifi Alive", //task name
    5000, //stack size increase above 1000 for connect to wifi
    NULL, //task parameters
    2, //priority
    NULL, //task handle
    CONFIG_ARDUINO_RUNNING_CORE //CPU Core 
  );
}

// MQTT-berichtverwerking
void callback(char* topic, byte* message, unsigned int length) {
  String topicString = String(topic);
      // Convert byte array to String
    String messageString;
    for (int i = 0; i < length; i++) {
        messageString += (char)message[i];
    }
  Serial.print("Bericht ontvangen op onderwerp: ");
  Serial.print(topic);
  Serial.print(". Bericht: ");

  // Toon het ontvangen bericht
  for (int i = 0; i < length; i++) {
    Serial.print((char)message[i]);
  }
  Serial.println();
  Serial.println(topic);
  if(topicString.indexOf("rgb") > 0){
    char copy[256];  // Maak een kopie van het bericht om strtok veilig te gebruiken
    strncpy(copy, (char*)message, length);
    copy[length] = '\0';  // Zorg ervoor dat de kopie een null-terminator heeft
    
    // Parse het ontvangen bericht om kleurwaarden te verkrijgen
    char* ptr = strtok(copy, ",");
    char *colors[3]; // Een array van pointers naar de delen van het bovenstaande array na strtok()
    colors[0] = 0;
    colors[1] = 0;
    colors[2] = 0;
  
    byte index = 0;
  
    // Splits het bericht op in RGB-kleurwaarden
    while (ptr != NULL) {
      colors[index] = ptr;
      index++;
      ptr = strtok(NULL, ",");
    }
  
    // Converteer de kleurwaarden naar integer
    r = atoi(colors[0]);
    g = atoi(colors[1]);
    b = atoi(colors[2]);
  
    //rgb to rgbw
    auto c = converter.RGBToRGBW(r, g, b);
    r = c.r;
    g = c.g;
    b = c.b;
    w = c.w;
  
    Serial.println(r);
    Serial.println(g);
    Serial.println(b);
    Serial.println(w);
  
    // Schrijf kleurwaarden naar EEPROM
    EEPROM.write(0, r);
    EEPROM.write(1, g);
    EEPROM.write(2, b);
    EEPROM.write(3, w);
    EEPROM.commit();
  
    // Stel de LED-kleur in
    setColor(r, g, b, w);
  }
  if(topicString.indexOf("name") > 0){
    friendlyName = messageString;
    Serial.println(friendlyName);
      saveStringToEEPROM(4, "name:" + friendlyName);
    Serial.println(friendlyName);
    EEPROM.commit();
  }

   if(topicString.indexOf("visualize") > 0){
    visualize();
   }
}

void visualize(){
  for(int i = 0; i < 10; i++){
    setColor(255,255,255,255);
    delay(500);
    setColor(0,0,0,0);
    delay(500);
  }
}


// MQTT-herverbinding
void reconnect() {
  // Blijf proberen totdat we opnieuw verbonden zijn
  while (!client.connected()) {
    Serial.print("Poging tot MQTT-verbinding...");
    Serial.print("Verbinding maken: ");
    Serial.print(WiFi.macAddress().c_str());
    Serial.print(" : ");
    Serial.print(Config::MQTT_PASS);

    // Probeer opnieuw verbinding te maken met MQTT-broker
    if (client.connect(WiFi.macAddress().c_str(), WiFi.macAddress().c_str(), Config::MQTT_PASS)) {
      Serial.println(" verbonden");
      // Abonneer op het juiste onderwerp
      client.subscribe((topic + '/' + convertMac() + "/rgb").c_str());
      client.subscribe((topic + '/' + convertMac() + "/name").c_str());
      client.subscribe((topic + '/' + convertMac() + "/visualize").c_str());
      sendAlive();
    } else {
      Serial.print("Mislukt, rc=");
      Serial.print(client.state());
      Serial.println(" probeer opnieuw over 5 seconden");
      delay(5000); // Wacht 5 seconden voordat u opnieuw probeert
    }
  }
}

// Stel de LED-kleur in
void setColor(int r, int g, int b, int w) {
  for (int pixel = 0; pixel < NUM_PIXELS; pixel++) {
    sk6812.setPixelColor(pixel, sk6812.Color(r, g, b, w));
  }
}

// Stuur "alive" bericht naar MQTT-broker
void sendAlive() {
  String currentMac = WiFi.macAddress();

  // Controleer of het MAC-adres het juiste formaat heeft (12 karakters, hexadecimaal)
  if (currentMac.length() == 17) {
    StaticJsonDocument<200> device;
    device["macAddress"] = currentMac.c_str();
    device["name"] = friendlyName;
    
    char out[128];
    serializeJson(device, out);
    client.publish((topic + "/alive").c_str(), out);
  } else {
    Serial.println("Ongeldig MAC-adres formaat. Bericht niet verzonden.");
  }
}
// Hulpmethode om MAC-adres te converteren naar een leesbaar formaat
String convertMac() {
  String macAddress = WiFi.macAddress();
  String cleanedMac = "";

  // Loop door elk teken van het MAC-adres
  for (int i = 0; i < macAddress.length(); i++) {
    char c = macAddress.charAt(i);

    // Voeg tekens toe aan de schoongemaakte string als ze geen ":" zijn
    if (c != ':') {
      cleanedMac += c;
    }
  }

  return cleanedMac;
}


//------------------------------------WIFI KEEP ALIVE CODE--------------------------------------------------------
void keepWifiAlive(void * parameters){ 
  for(;;){
    //if connected do nothing and quit
    if(WiFi.status() == WL_CONNECTED){
      Serial.print("WiFi still connected: "); Serial.println(WiFi.localIP().toString().c_str());
      vTaskDelay(10000 / portTICK_PERIOD_MS);
      continue;
    }
    //initiate connection

       StaticJsonDocument<1024> jsonLogins;
    DeserializationError error = deserializeJson(jsonLogins, Config::LOGINS);
    
    if (error) {
      Serial.print("Fout tijdens het analyseren van JSON: ");
      Serial.println(error.c_str());
      return;
    }
    
    Serial.println("Wifi Connecting");
    Serial.println(Config::WIFI_SSID);
    Serial.println(String(WiFi.macAddress()));

    // Controleer of de sleutel bestaat voordat je de waarde probeert af te drukken
    if (jsonLogins.containsKey(String(WiFi.macAddress()))) {
      Serial.print("Value for ");
      Serial.print(WiFi.macAddress());
      Serial.print(": ");
      Serial.println(jsonLogins[String(WiFi.macAddress())].as<const char*>());
    } else {
      Serial.println("Key not found in JSON document");
      return;
    }

    WiFi.mode(WIFI_STA);
    WiFi.begin(Config::WIFI_SSID, jsonLogins[String(WiFi.macAddress())].as<const char*>());
    unsigned long startAttemptTime = millis();

    //Indicate to the user that we are not currently connected but are trying to connect.
    while (WiFi.status() != WL_CONNECTED && millis() - startAttemptTime < WIFI_TIMEOUT_MS){
      Serial.print(".");
      vTaskDelay(500 / portTICK_PERIOD_MS);
      vTaskDelay(500 / portTICK_PERIOD_MS);
      continue;
    }
    //Indicate to the user the outcome of our attempt to connect.
    if(WiFi.status() == WL_CONNECTED){
      Serial.print("[WIFI] Connected: "); Serial.println(WiFi.localIP().toString().c_str());
      reconnect();
    } else {
      Serial.println("[WIFI] Failed to Connect before timeout");
    }
  }
}  
//---------------------------------END OF WIFI KEEP ALIVE CODE--------------------------------------------------------

//---------------------------------CHECK SENSOR INPUT-----------------------------------------------------------------

void checkSensor(void * parameters){
    for(;;){
  // Lees de sensorwaarde
  int val = digitalRead(sensorpin);
  // Vergelijk huidige sensorwaarde met vorige waarde
  if (val != prevVal) {
    prevVal = val;
    if (val == 1) {
      // Zet LED-kleur en stuur "alive" bericht als sensor is geactiveerd
      setColor(r, g, b, w);
      sendAlive();
    } else {
      // Zet LED-kleur uit als sensor niet is geactiveerd
      setColor(0, 0, 0, 0);
    }
  }
  // Toon de LED-kleuren op de sk6812 LED-strip
  sk6812.show();
    }
}

//---------------------------------END CHECK SENSOR INPUT-------------------------------------------------------------

void saveStringToEEPROM(int address, String data) {
  int length = data.length();

  for (int i = 0; i < length; i++) {
    EEPROM.write(address + i, data[i]);
  }

  EEPROM.write(address + length, '\0'); // Null-terminator om het einde van de string aan te geven
  EEPROM.commit(); // Belangrijk: om de wijzigingen op te slaan
}

String readStringFromEEPROM(int address) {
  String data;

  for (int i = 0; i < 100; i++) {  // Maximaal aantal tekens om te lezen om oneindige lussen te voorkomen
    char readChar = EEPROM.read(address + i);
    if (readChar == '\0') {
      break;  // Stoppen bij het bereiken van het nul-terminatiekarakter
    }

    // Print de hexadecimale waarde van de byte
    Serial.print("Byte ");
    Serial.print(i);
    Serial.print(": 0x");
    Serial.println(readChar, HEX);

    data += readChar;
  }

  Serial.println("Data gelezen van EEPROM: " + data);

  return data;
}

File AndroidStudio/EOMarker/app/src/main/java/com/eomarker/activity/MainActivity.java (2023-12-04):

package com.eomarker.activity;

import android.annotation.SuppressLint;
import android.content.Intent;
import android.graphics.Color;
import android.os.Bundle;
import android.util.Log;
import android.view.Menu;
import android.view.MenuItem;
import android.view.MotionEvent;
import android.view.WindowManager;
import android.widget.CheckBox;
import android.widget.Spinner;
import android.widget.Toast;

import androidx.appcompat.app.AppCompatActivity;
import androidx.swiperefreshlayout.widget.SwipeRefreshLayout;

import com.eomarker.R;
import com.eomarker.device.Device;
import com.eomarker.device.DeviceDiscoveryListener;
import com.eomarker.device.SpinnerDeviceAdapter;
import com.eomarker.mqtt.MqttHandler;
import com.eomarker.storage.InternalStorage;
import com.eomarker.storage.KeyValueStorage;
import com.skydoves.colorpickerview.ColorEnvelope;
import com.skydoves.colorpickerview.ColorPickerView;
import com.skydoves.colorpickerview.listeners.ColorEnvelopeListener;

import java.util.List;

public class MainActivity extends AppCompatActivity implements DeviceDiscoveryListener {

    private static final String TAG = MainActivity.class.getSimpleName();
    private static String BROKER_URL = "";
    private static String CLIENT_ID = "";
    private static String CLIENT_PASS = "";
    private static MqttHandler mqttHandler;
    private boolean firstStart = true;

    String macAddress = "";
    private List<Device> devices;


    @SuppressLint("ClickableViewAccessibility")
    @Override
    protected void onCreate(Bundle savedInstanceState) {
        super.onCreate(savedInstanceState);
        setContentView(R.layout.activity_main);
        getWindow().addFlags(WindowManager.LayoutParams.FLAG_KEEP_SCREEN_ON);
        mqttHandler = new MqttHandler();
        mqttHandler.setDeviceDiscoveryListener(this);


        initializeBrokerInfo();
        ConnectMQTT();
        updateStatus();
        setupColorPicker();
        setupPullToRefresh();
        loadDevices();
    }

    private void initializeBrokerInfo() {
        BROKER_URL = "tcp://" + KeyValueStorage.loadData(getApplicationContext(), "BROKER_URL", getResources().getString(R.string.MQTT_BROKER));
        CLIENT_ID = KeyValueStorage.loadData(getApplicationContext(), "BROKER_USERNAME", getResources().getString(R.string.MQTT_BROKER));
        CLIENT_PASS = KeyValueStorage.loadData(getApplicationContext(), "BROKER_PASSWORD", getResources().getString(R.string.MQTT_BROKER));
    }

    @SuppressLint("ClickableViewAccessibility")
    private void setupColorPicker() {
        SwipeRefreshLayout swipeRefreshLayout = findViewById(R.id.pullToRefresh);
        ColorPickerView colorPickerView = findViewById(R.id.colorPickerView);
        colorPickerView.setOnTouchListener((v, event) -> {
            int action = event.getAction();
            switch (action) {
                case MotionEvent.ACTION_DOWN:
                    // Start veegbeweging
                    swipeRefreshLayout.setEnabled(false);
                    break;
                case MotionEvent.ACTION_UP:
                    // Eind veegbeweging
                    swipeRefreshLayout.setEnabled(true);
                    break;
            }
            return false;
        });
        colorPickerView.setColorListener(new ColorEnvelopeListener() {
            @Override
            public void onColorSelected(ColorEnvelope color, boolean fromUser) {
                if (!firstStart) {
                    CheckBox ColorAll = findViewById(R.id.CBColorAll);
                    if(ColorAll.isChecked()){
                        handleColorSelectionAll(color);
                    }else {
                        handleColorSelection(color);
                    }
                }
                firstStart = false;
            }
        });
    }

    private void setupPullToRefresh() {
        SwipeRefreshLayout pullToRefresh = findViewById(R.id.pullToRefresh);
        pullToRefresh.setOnRefreshListener(() -> {
            loadDevices();
            pullToRefresh.setRefreshing(false);
        });
    }

    private void handleColorSelection(ColorEnvelope color) {
        Spinner spinnerDevices = findViewById(R.id.spinner_devices);
        try {
            Device device = (Device) spinnerDevices.getSelectedItem();
            macAddress = device.macAddress;
        } catch (Exception e) {
            Log.e(TAG, "Error getting selected device", e);
        }

        if (android.os.Build.VERSION.SDK_INT >= android.os.Build.VERSION_CODES.O) {
            updateColor(String.valueOf(Color.red(color.getColor())), String.valueOf(Color.green(color.getColor())), String.valueOf(Color.blue(color.getColor())), "0");
        }
    }

    private void handleColorSelectionAll(ColorEnvelope color) {
        loadDevices();
        for(Device device : devices){
            macAddress = device.macAddress;
            if (android.os.Build.VERSION.SDK_INT >= android.os.Build.VERSION_CODES.O) {
                updateColor(String.valueOf(Color.red(color.getColor())), String.valueOf(Color.green(color.getColor())), String.valueOf(Color.blue(color.getColor())), "0");
            }
        }
    }

    public void loadDevices() {
        Spinner spinnerDevices = findViewById(R.id.spinner_devices);
        InternalStorage internalStorage = new InternalStorage(this);
        devices = internalStorage.getDevices();

        SpinnerDeviceAdapter adapter = new SpinnerDeviceAdapter(this, R.layout.spinner_device_item, R.id.spinner_device_macAddress, devices);
        spinnerDevices.setAdapter(adapter);
    }

    @Override
    protected void onDestroy() {
        mqttHandler.disconnect();
        super.onDestroy();
    }

    private void publishMessage(String topic, String message) {
        if (mqttHandler.connected()) {
            mqttHandler.publish(topic, message);
        }
    }

    private void updateColor(String red, String green, String blue, String white) {
        updateStatus();
        String color = red + "," + green + "," + blue;
        try {
            String mac = macAddress.replace(":", "");
            publishMessage("PM/EOMarkers/" + mac + "/rgb", color);
        } catch (Exception e) {
            Log.e(TAG, "Error updating color", e);
        }
    }

    @Override
    public boolean onCreateOptionsMenu(Menu menu) {
        getMenuInflater().inflate(R.menu.menu_main, menu);
        return true;
    }

    @Override
    public boolean onOptionsItemSelected(MenuItem item) {
        int id = item.getItemId();
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

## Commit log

2023-09-25 Added affiche
    [PCB.kicad_pcb, PCB.kicad_sch]
2023-09-25 Elektrisch schema first draft
    [Elektrisch schema.kicad_pcb, Elektrisch schema.kicad_sch]
2023-09-25 elektisch shema second draft
    [Elektrisch schema.csv, Elektrisch schema.kicad_pcb, Elektrisch schema.kicad_sch]
2023-10-02 toevoeging 3d tekening
    [bottom.stl, main part.stl]
2023-10-02 updated 3d tekening
    [main part.stl]
2023-10-02 updating github
    [Elektrisch schema.kicad_sch]
2023-10-02 3d tekening aangepast + 2d tekening
    [EO.dxf, main part.stl]
2023-10-09 Added arduino program
2023-10-09 PCB getekend
    [EO.dxf, PCB.kicad_pcb, PCB.kicad_sch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]
2023-10-09 created app to control leds
2023-10-16 added config file to arduino
2023-10-16 deleted unused pcb files
    [PCB.kicad_pcb, PCB.kicad_sch, bom.csv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]
2023-10-16 updated arduino
2023-10-16 Readme bijgevuld en schema gemaakt
    [Elektrisch schema.kicad_sch, PCB.kicad_pcb]
2023-10-19 cleaned arduino code
2023-10-30 3d drawing updated
    [bottom.stl, main part.stl]
2023-11-05 adding arduino flowchart
2023-11-05 editing arduino flowchart
2023-11-06 Added broker url to strings file
    [EO-Markers.ino]
2023-11-06 added support for USB-C port
    [bottom.stl]
2023-11-06 shortened the pillar for space for the batterypack
    [main part.stl]
2023-11-06 3d drawing adjusted for 4th slide
    [bottom.stl, main part.stl]
2023-11-06 added device dropdown to app
2023-11-06 made more space for sensor
    [main part.stl]
2023-11-06 plaats voor schakelaar
    [bottom.stl]
2023-11-13 added device ab to app
2023-12-10 re naming arduino example config file
2023-12-10 adding more pcb versions and a readme with explenation
    [PCB.csv, PCB.kicad_pcb, PCB.kicad_sch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]
2023-12-11 Delete Elektrisch schema directory
    redundant already in pcb folder
    [Elektrisch schema.csv, Elektrisch schema.kicad_pcb, Elektrisch schema.kicad_sch]
2023-12-11 adding readmes in arduino and androidstudio folders
2023-12-11 readme 3d tekening
    [EO.dxf, bottom.stl]
2023-12-11 Fixed arduino + android code
    [MainActivity.java]
